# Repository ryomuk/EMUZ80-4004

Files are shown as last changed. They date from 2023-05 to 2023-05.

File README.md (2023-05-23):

# EMUZ80-4004
4004 mezzanine board for EMUZ80

This document is written mostly in Japanese. If necessary, please use a translation service such as DeepL (I recommend this) or Google.

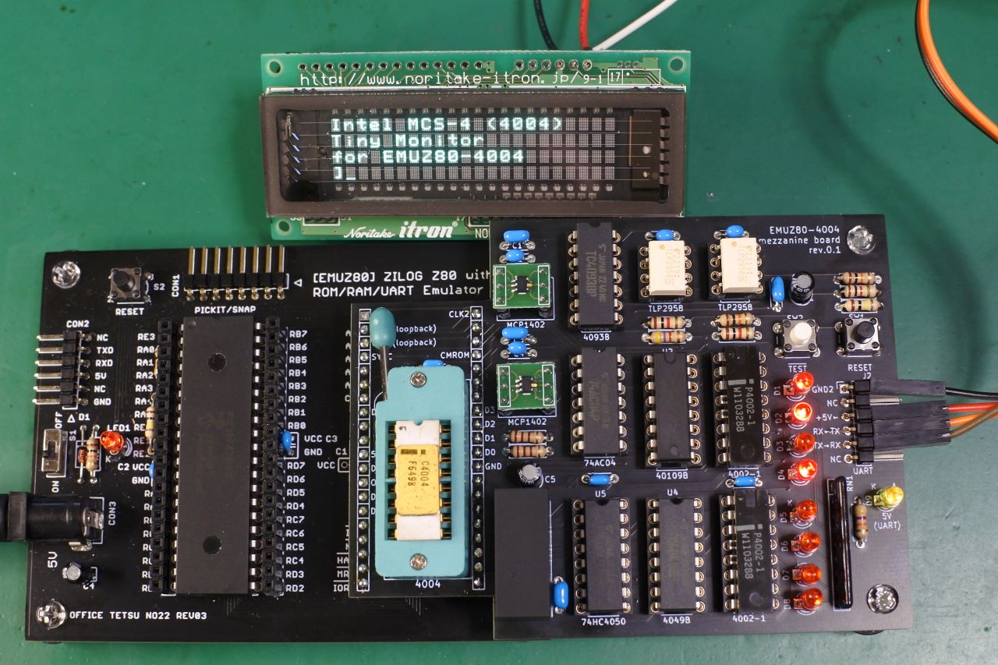
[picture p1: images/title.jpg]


## 概要
電脳伝説さん(@vintagechips)のEMUZ80( https://github.com/vintagechips/emuz80 )のZ80をIntel4004に差し替えるための基板(メザニンボード)，PIC用ファームウェア，4004用のデモプログラム(電卓)です．

別レポジトリにあるIntel4004評価ボード(test4004 https://github.com/ryomuk/test4004 )の4289とROMの機能をPIC上に実装したような作りになっています．
プログラムメモリ領域のRAMは実装しておらず，データ用メモリ(4002)も2つしか搭載していないので，test4004よりも小規模なシステムですが，とりあえずデモプログラムとして電卓が動作しています．

## このレポジトリの内容
- hardware/rev0.1 : メザニンボード作成用ファイル一式(KiCad 7用)
- src/PIC/emuz80_4004.X : PIC用ファームウェア(MPLAB IDE用のプロジェクトフォルダ)
- src/demo/calc : 電卓のデモプログラム(4004アセンブラ)

## 動画
Youtubeで関連動画を公開しています．
- https://www.youtube.com/@ryomukai/videos

## ブログ
関連する情報が書いてあるかも．
- [Intel 4004 関連記事の目次@ブログの練習](https://blog.goo.ne.jp/tk-80/e/3fa1e2972737c7b7d1b83f4e7bd648a2)

## 開発環境
- [The Macroassembler AS](http://john.ccac.rwth-aachen.de:8000/as/)
- [Microchip MPLAB IDE](https://www.microchip.com/en-us/tools-resources/develop/mplab-x-ide)

## 参考にした文献，サイト等 (敬称略, 順不同)
- vintagechips, [emuz80](https://github.com/vintagechips/emuz80)
- vintagechips, [EMUZ80が完成](https://vintagechips.wordpress.com/2022/03/05/emuz80_reference/)
- satoshiokue, [EMUZ80-6502](https://github.com/satoshiokue/EMUZ80-6502)． 他，各種メザニンボード
- Gazelle, [EMUZ80用ファームウェア](https://drive.google.com/drive/folders/1NaIIpzsUY3lptekcrJjwyvWTBNHIjUf1)
- kanpapa, [emu1802](https://github.com/kanpapa/emu1802)
- yyhayami, [emuz80_yyhayami](https://github.com/yyhayami/emuz80_yyhayami)

## 更新履歴
- 2023/5/23: 初版公開

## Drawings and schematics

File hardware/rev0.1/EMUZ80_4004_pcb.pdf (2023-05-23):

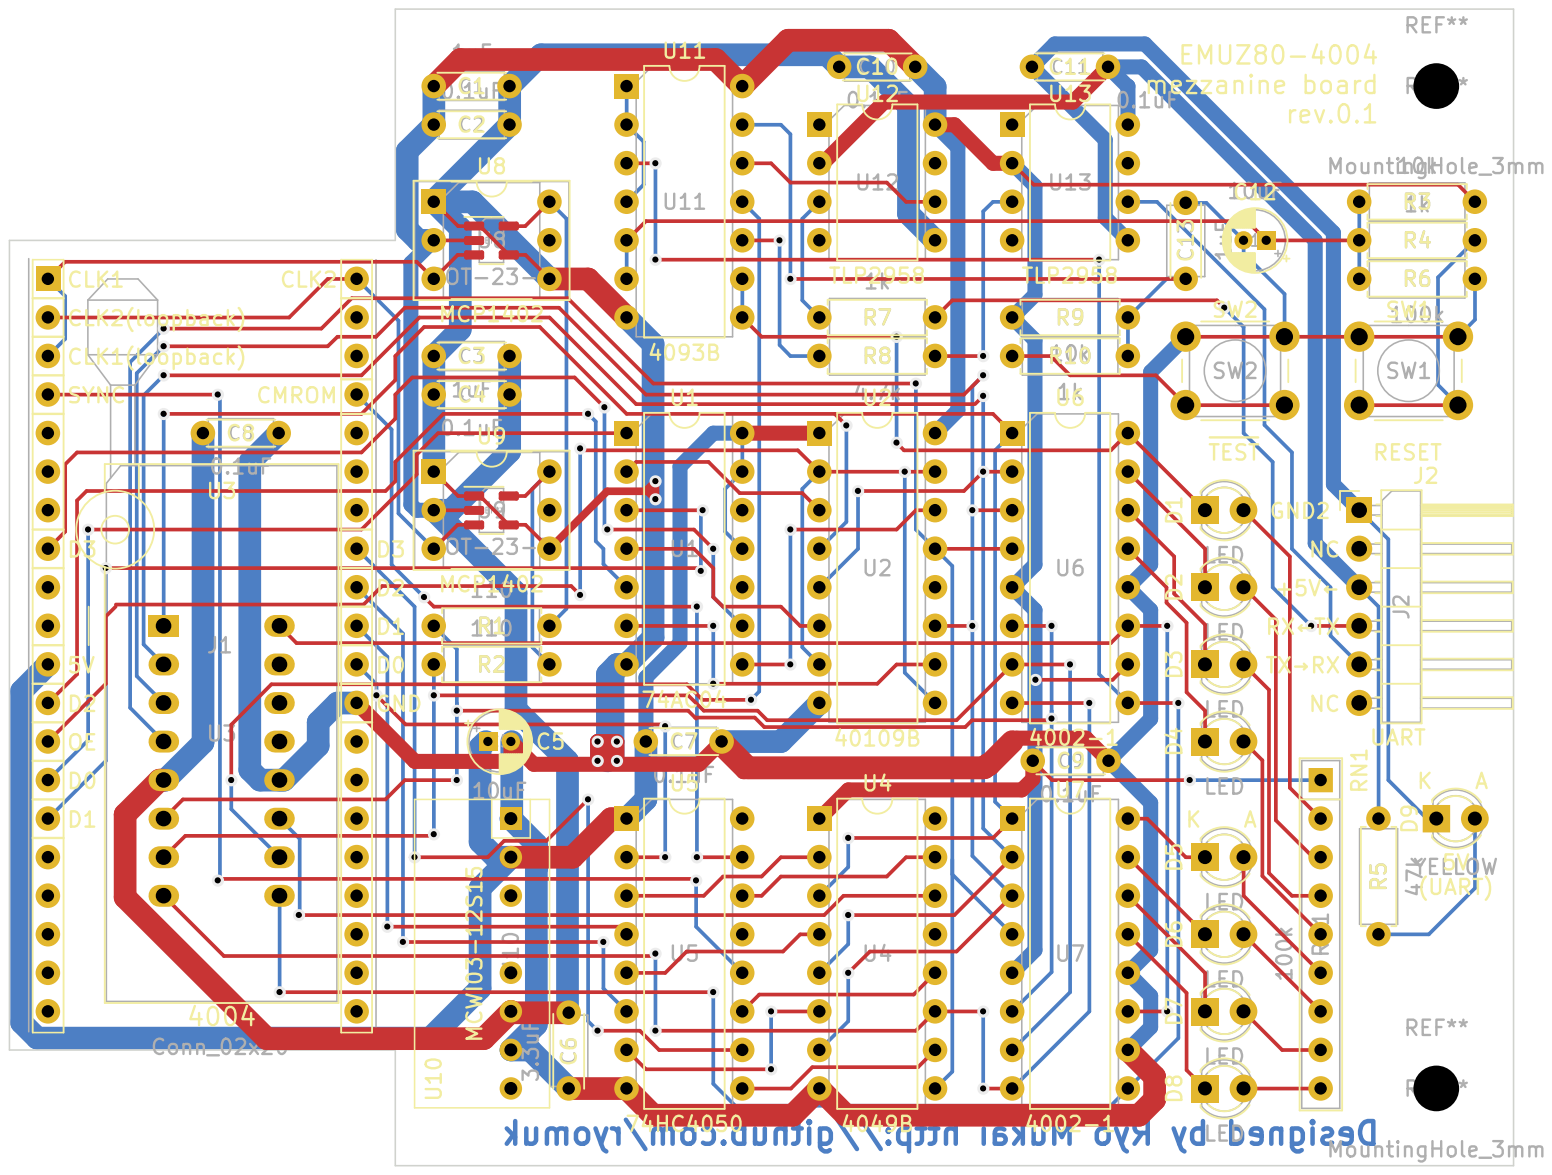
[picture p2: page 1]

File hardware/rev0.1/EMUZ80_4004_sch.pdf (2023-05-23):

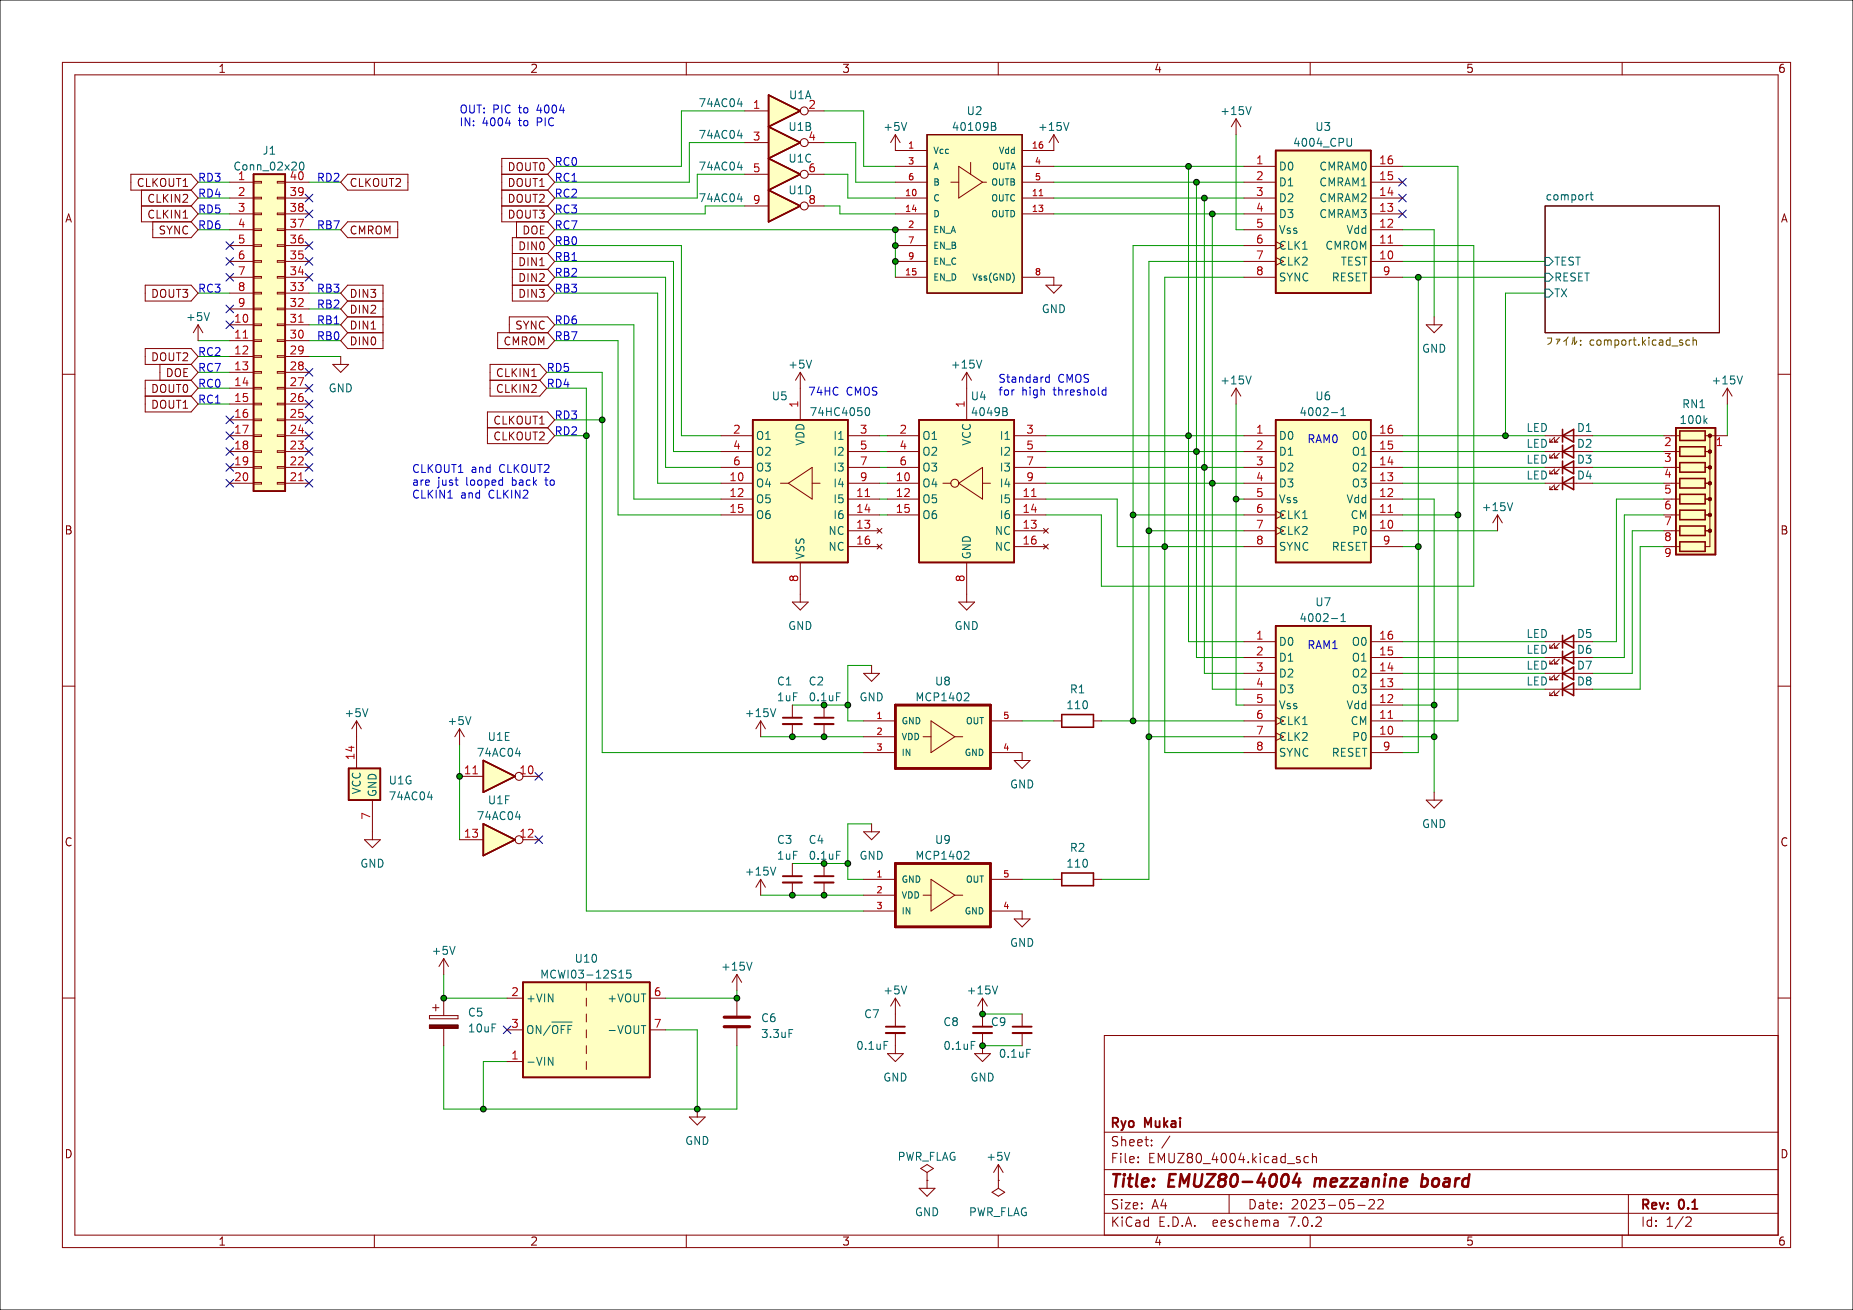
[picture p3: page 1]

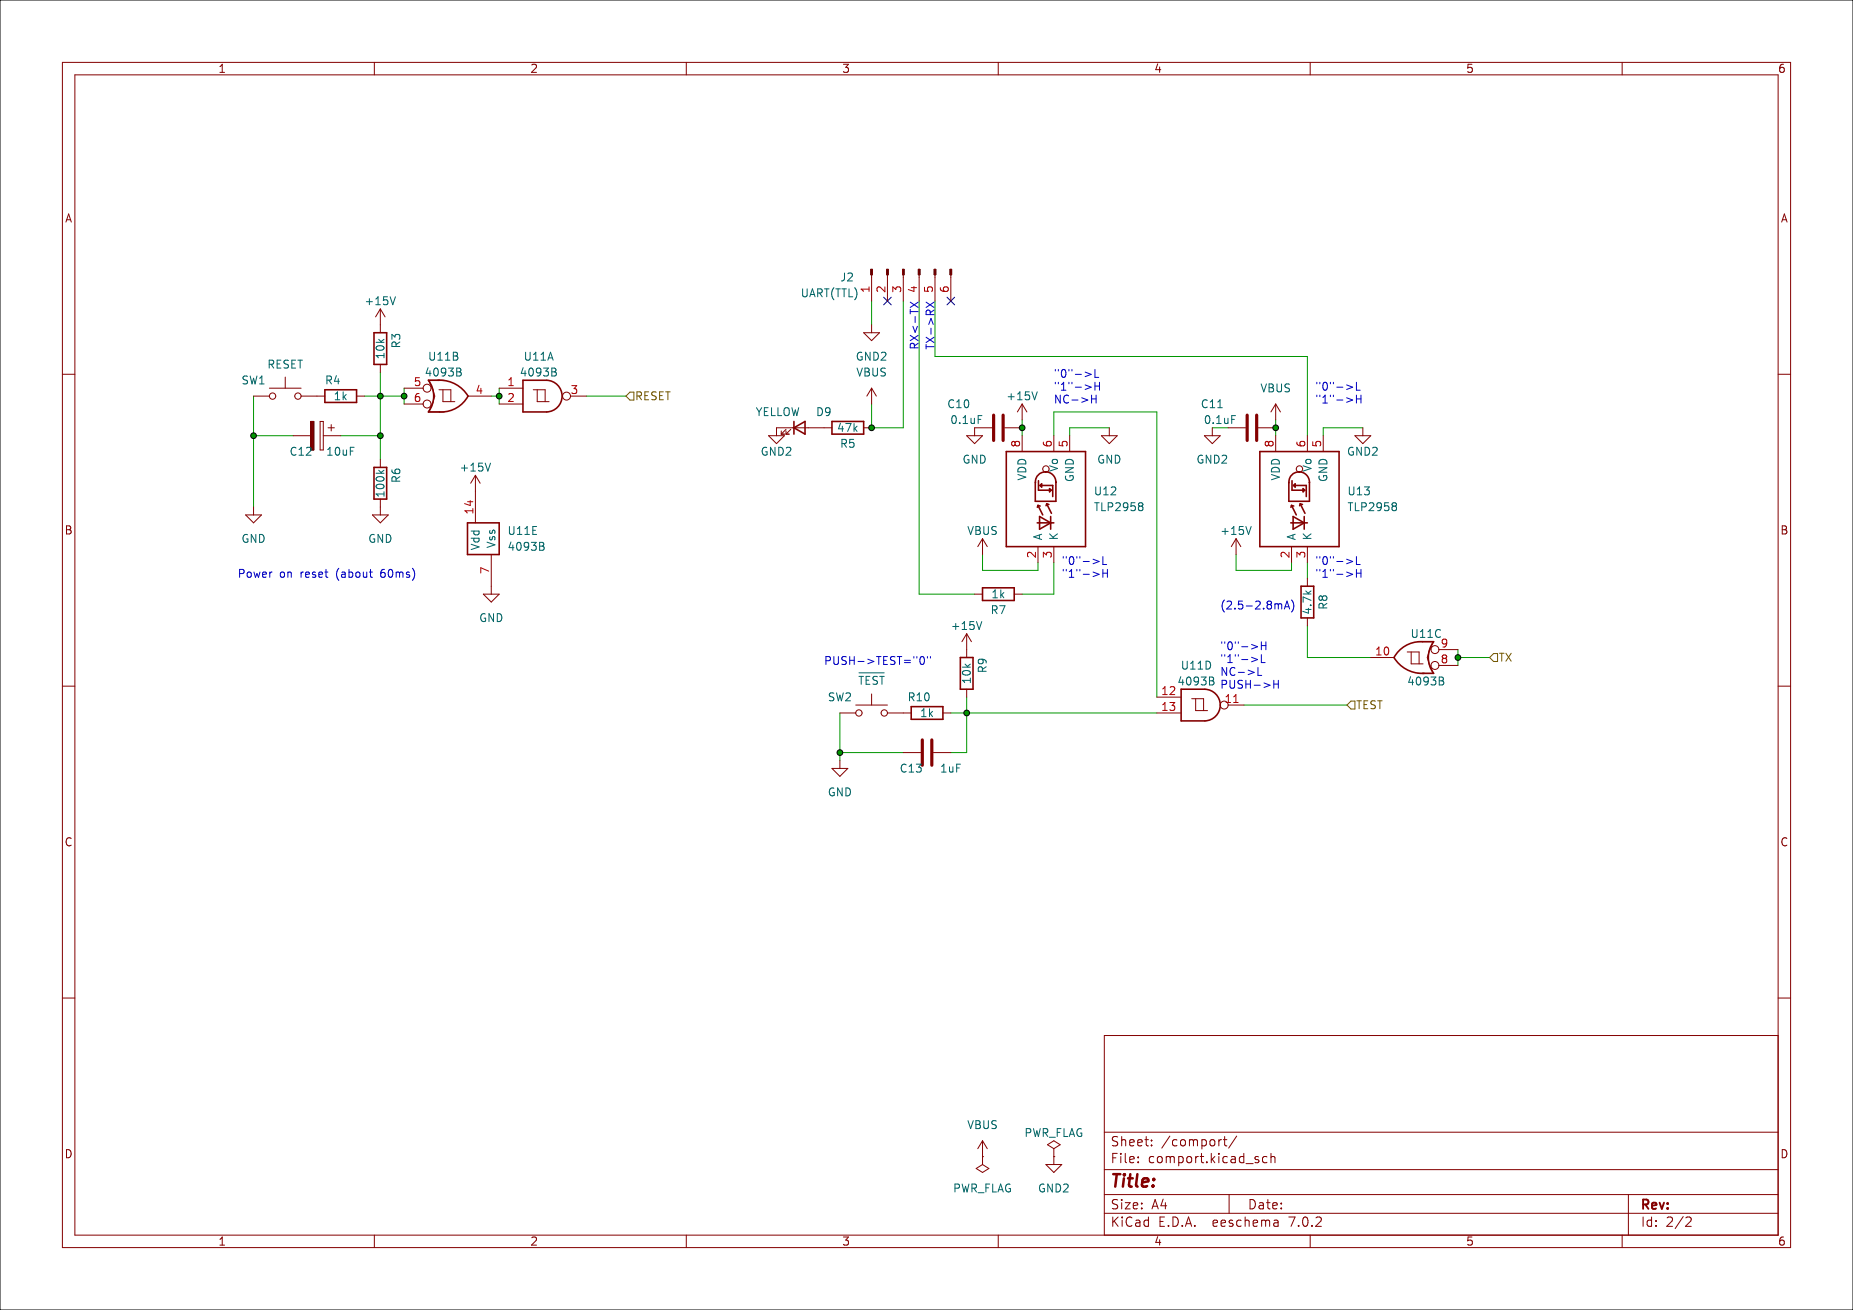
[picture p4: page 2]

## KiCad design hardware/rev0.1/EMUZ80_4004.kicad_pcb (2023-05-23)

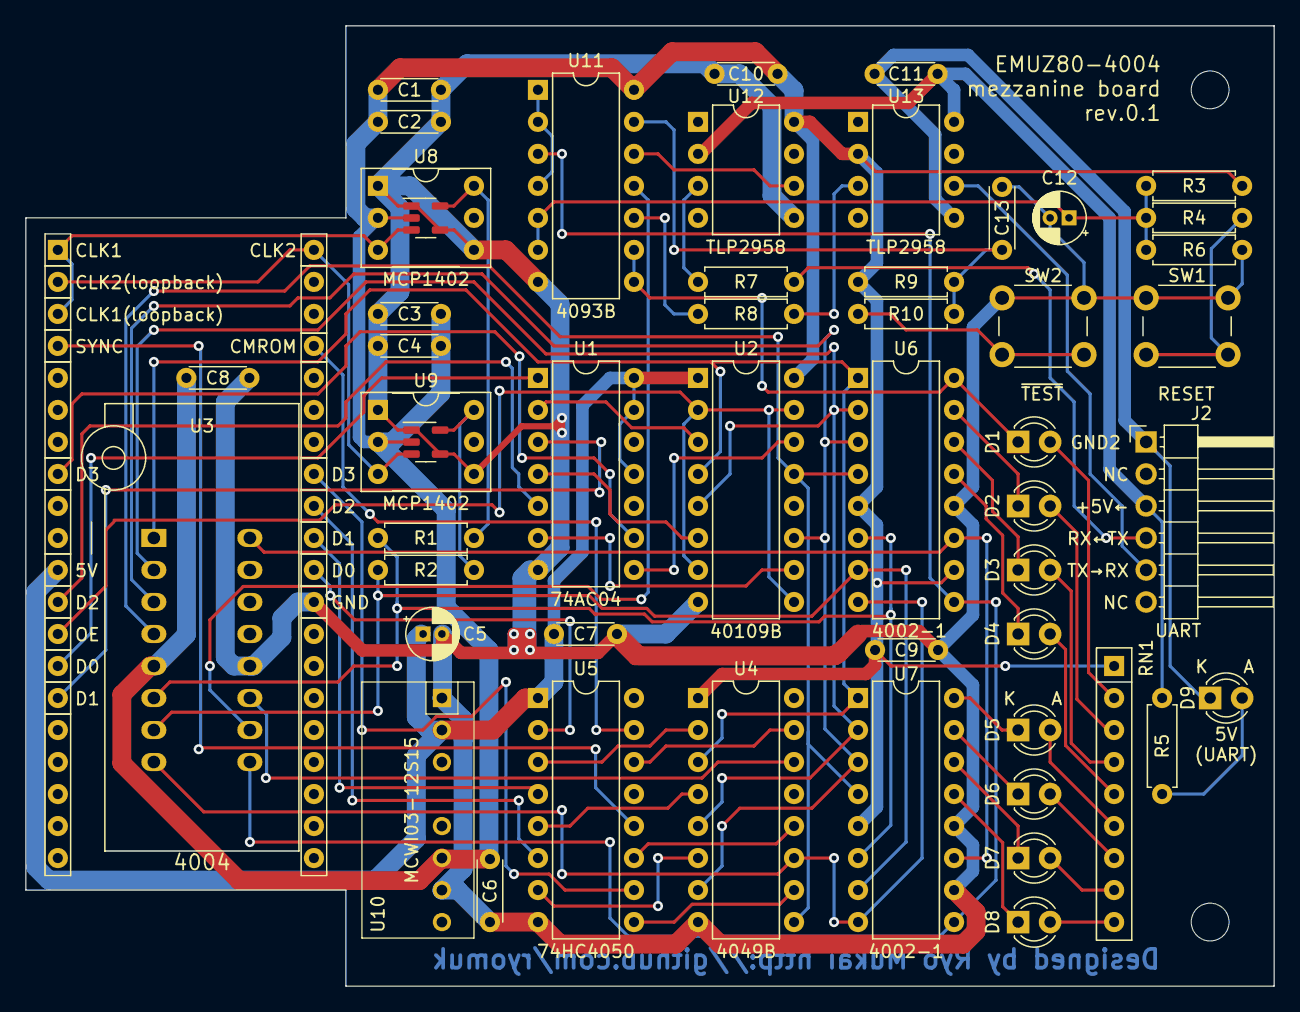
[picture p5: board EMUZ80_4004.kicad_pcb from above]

Board: 2 copper layers, 99.1 x 76.2 mm, 50 parts (0 on the bottom side), 69 nets.

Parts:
C1, C3: 1uF; C_Disc_D4.3mm_W1.9mm_P5.00mm
C2, C4, C7, C8, C9, C10, C11: 0.1uF; C_Disc_D4.3mm_W1.9mm_P5.00mm
C5, C12: 10uF; CP_Radial_D4.0mm_P1.50mm
C6: 3.3uF; C_Disc_D4.7mm_W2.5mm_P5.00mm
C13: 1uF; C_Disc_D4.7mm_W2.5mm_P5.00mm
D1, D2, D3, D4, D5, D6, D7, D8: LED; LED_D3.0mm
D9: YELLOW; LED_D3.0mm
J1: Conn_02x20; DIP-40_W20.32mm800mil_Socket
J2: UART; PinHeader_1x06_P2.54mm_Horizontal
R1, R2: 110; R_Axial_DIN0207_L6.3mm_D2.5mm_P7.62mm_Horizontal
R3, R9: 10k; R_Axial_DIN0207_L6.3mm_D2.5mm_P7.62mm_Horizontal
R4, R7, R10: 1k; R_Axial_DIN0207_L6.3mm_D2.5mm_P7.62mm_Horizontal
R5: 47k; R_Axial_DIN0207_L6.3mm_D2.5mm_P7.62mm_Horizontal
R6: 100k; R_Axial_DIN0207_L6.3mm_D2.5mm_P7.62mm_Horizontal
R8: 4.7k; R_Axial_DIN0207_L6.3mm_D2.5mm_P7.62mm_Horizontal
RN1: 100k; R_Array_SIP9
SW1: RESET; SW_PUSH_6mm_H4.3mm
SW2: ~{TEST}; SW_PUSH_6mm_H4.3mm
U1: 74AC04; DIP-14_W7.62mm
U2: 40109B; DIP-16_W7.62mm
U3: 4004; DIP_Socket-16_W4.3_W5.08_W7.62_W10.16_W10.9_3M_216-3340-00-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
U4: 4049B; DIP-16_W7.62mm
U5: 74HC4050; DIP-16_W7.62mm
U6, U7: 4002-1; DIP-16_W7.62mm
U8, U9: MCP1402; DIP-6_W7.62mm_Socket_5pin
U10: MCWI03-12S15; SIP-8_without4pin_for_DCDC
U11: 4093B; DIP-14_W7.62mm
U12, U13: TLP2958; DIP-8_W7.62mm

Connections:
+5V: C5.1, C7.1, J1.11, U1.11, U1.13, U1.14 (VCC), U2.1 (Vcc), U5.1 (VDD), U10.2 (+VIN)
+15V: C1.2, C2.2, C3.2, C4.2, C6.1, C8.1, C9.1, C10.2, R3.1, R9.1, RN1.1 (common), U2.16 (Vdd), U3.5 (Vss), U4.1 (VCC), U6.5 (Vss), U6.10 (P0), U7.5 (Vss), U8.2 (VDD), U9.2 (VDD), U10.6 (+VOUT), U11.14 (Vdd), U12.8 (VDD), U13.2 (A)
/comport/RESET: U3.9 (RESET), U6.9 (RESET), U7.9 (RESET), U11.3
/comport/TEST: U3.10 (TEST), U11.11
/comport/TX: D1.1 (K), U6.16 (O0), U11.8, U11.9
CLKIN1: J1.1, J1.3, U8.3 (IN)
CLKIN2: J1.2, J1.40, U9.3 (IN)
CMROM: J1.37, U5.15 (O6)
DIN0: J1.30, U5.2 (O1)
DIN1: J1.31, U5.4 (O2)
DIN2: J1.32, U5.6 (O3)
DIN3: J1.33, U5.10 (O4)
DOE: J1.13, U2.2 (EN_A), U2.7 (EN_B), U2.9 (EN_C), U2.15 (EN_D)
DOUT0: J1.14, U1.1
DOUT1: J1.15, U1.3
DOUT2: J1.12, U1.5
DOUT3: J1.8, U1.9
GND: C1.1, C2.1, C3.1, C4.1, C5.2, C6.2, C7.2, C8.2, C9.2, C10.1, C12.2, C13.2, J1.29, R6.2, SW1.1, SW2.1, U1.7 (GND), U2.8 (Vss(GND)), U3.12 (Vdd), U4.8 (GND), U5.8 (VSS), U6.12 (Vdd), U7.10 (P0), U7.12 (Vdd), U8.1 (GND), U8.4 (GND), U9.1 (GND), U9.4 (GND), U10.1 (-VIN), U10.7 (-VOUT), U11.7 (Vss), U12.5 (GND)
GND2: C11.1, D9.1 (K), J2.1, U13.5 (GND)
unnamed: C12.1, R3.2, R4.2, R6.1, U11.5, U11.6
unnamed: C13.1, R9.2, R10.2, U11.13
unnamed: D1.2 (A), RN1.2 (R1)
unnamed: D2.2 (A), RN1.3 (R2)
unnamed: D2.1 (K), U6.15 (O1)
unnamed: D3.2 (A), RN1.4 (R3)
unnamed: D3.1 (K), U6.14 (O2)
unnamed: D4.2 (A), RN1.5 (R4)
unnamed: D4.1 (K), U6.13 (O3)
unnamed: D5.2 (A), RN1.6 (R5)
unnamed: D5.1 (K), U7.16 (O0)
unnamed: D6.2 (A), RN1.7 (R6)
unnamed: D6.1 (K), U7.15 (O1)
unnamed: D7.2 (A), RN1.8 (R7)
unnamed: D7.1 (K), U7.14 (O2)
unnamed: D8.2 (A), RN1.9 (R8)
unnamed: D8.1 (K), U7.13 (O3)
unnamed: D9.2 (A), R5.1
unnamed: J2.4, R7.1
unnamed: J2.5, U13.6 (Vo)
unnamed: R4.1, SW1.2
unnamed: R8.1, U11.10
unnamed: R10.1, SW2.2
unnamed: U1.2, U2.3 (A)
unnamed: U1.4, U2.6 (B)
unnamed: U1.6, U2.10 (C)
unnamed: U1.8, U2.14 (D)
unnamed: U2.4 (OUTA), U3.1 (D0), U4.3 (I1), U6.1 (D0), U7.1 (D0)
unnamed: U2.5 (OUTB), U3.2 (D1), U4.5 (I2), U6.2 (D1), U7.2 (D1)
unnamed: U2.11 (OUTC), U3.3 (D2), U4.7 (I3), U6.3 (D2), U7.3 (D2)
unnamed: U2.13 (OUTD), U3.4 (D3), U4.9 (I4), U6.4 (D3), U7.4 (D3)
unnamed: R1.2, U3.6 (CLK1), U6.6 (CLK1), U7.6 (CLK1)
unnamed: R2.2, U3.7 (CLK2), U6.7 (CLK2), U7.7 (CLK2)
unnamed: U3.16 (CMRAM0), U6.11 (CM), U7.11 (CM)
unnamed: U3.11 (CMROM), U4.14 (I6)
unnamed: U3.8 (SYNC), U4.11 (I5), U6.8 (SYNC), U7.8 (SYNC)
unnamed: U4.2 (O1), U5.3 (I1)
unnamed: U4.4 (O2), U5.5 (I2)
unnamed: U4.6 (O3), U5.7 (I3)
unnamed: U4.10 (O4), U5.9 (I4)
unnamed: U4.12 (O5), U5.11 (I5)
unnamed: U4.15 (O6), U5.14 (I6)
unnamed: R1.1, U8.5 (OUT)
unnamed: R2.1, U9.5 (OUT)
unnamed: U11.1, U11.2, U11.4
unnamed: R7.2, U12.3 (K)
unnamed: U11.12, U12.6 (Vo)
unnamed: R8.2, U13.3 (K)
SYNC: J1.4, U5.12 (O5)
VBUS: C11.2, J2.3, R5.2, U12.2 (A), U13.8 (VDD)

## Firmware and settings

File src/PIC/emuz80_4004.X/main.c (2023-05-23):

/**
  Generated Main Source File

  Company:
    Microchip Technology Inc.

  File Name:
    main.c

  Summary:
    This is the main file generated using PIC10 / PIC12 / PIC16 / PIC18 MCUs

  Description:
    This header file provides implementations for driver APIs for all modules selected in the GUI.
    Generation Information :
        Product Revision  :  PIC10 / PIC12 / PIC16 / PIC18 MCUs - 1.81.8
        Device            :  PIC18F47Q43
        Driver Version    :  2.00
*/

/*
    (c) 2018 Microchip Technology Inc. and its subsidiaries. 
    
    Subject to your compliance with these terms, you may use Microchip software and any 
    derivatives exclusively with Microchip products. It is your responsibility to comply with third party 
    license terms applicable to your use of third party software (including open source software) that 
    may accompany Microchip software.
    
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
    IN NO EVENT WILL MICROCHIP BE LIABLE FOR ANY INDIRECT, SPECIAL, PUNITIVE, 
    INCIDENTAL OR CONSEQUENTIAL LOSS, DAMAGE, COST OR EXPENSE OF ANY KIND 
    WHATSOEVER RELATED TO THE SOFTWARE, HOWEVER CAUSED, EVEN IF MICROCHIP 
    HAS BEEN ADVISED OF THE POSSIBILITY OR THE DAMAGES ARE FORESEEABLE. TO 
    THE FULLEST EXTENT ALLOWED BY LAW, MICROCHIP'S TOTAL LIABILITY ON ALL 
    CLAIMS IN ANY WAY RELATED TO THIS SOFTWARE WILL NOT EXCEED THE AMOUNT 
    OF FEES, IF ANY, THAT YOU HAVE PAID DIRECTLY TO MICROCHIP FOR THIS 
    SOFTWARE.
*/

#include "mcc_generated_files/mcc.h"

typedef unsigned char byte;
typedef unsigned short word;

#define waitForRise(x) do{while(x); while(!x);}while(0)
#define waitForFall(x) do{while(!x); while(x);}while(0)
#define waitForBecomeLow(x) while(x){}
#define waitForBecomeHigh(x) while(!x){}

#define CLK1 CLK1_GetValue()
#define CLK2 CLK2_GetValue()
#define SYNC SYNC_GetValue()
#define CMROM CMROM_GetValue()

#define ROM_SIZE 0x1000 // 4kbytes
extern const byte rom[];

/*
                         Main application
 */

#define CMROMpos 7
#define DOEpos 7
#define CMROMbit ((byte)1 << CMROMpos)
#define DOEbit ((byte)1 << DOEpos)
#define DOEmask ~DOEbit

byte cmrom, opr, opa;
byte address_l;
void main(void)
{
 
  // Initialize the device
  SYSTEM_Initialize();

  // If using interrupts in PIC18 High/Low Priority Mode you need to enable the Global High and Low Interrupts
  // If using interrupts in PIC Mid-Range Compatibility Mode you need to enable the Global Interrupts
  // Use the following macros to:
  
  // Enable high priority global interrupts
  //INTERRUPT_GlobalInterruptHighEnable();
  
  // Enable low priority global interrupts.
  //INTERRUPT_GlobalInterruptLowEnable();
  
  // Disable high priority global interrupts
  INTERRUPT_GlobalInterruptHighDisable();
  
  // Disable low priority global interrupts.
  INTERRUPT_GlobalInterruptLowDisable();
  
  // CPU cycles
  //     A1  A2  A3  M1  M2  X1  X2  X3
  //CLK1~\_/~\_/~\_/~\_/~\_/~\_/~\_/~\_/
  //CLK2/~\_/~\_/~\_/~\_/~\_/~\_/~\_/~\_
  //
  // 2 phase clocks
  //      6    0    1    2    3    4    5    6    0
  // CLK1 ~~~~~\_________/~~~~~~~~~~~~~~~~~~~~~~~~\____
  //
  // CLK2 /~~~~~~~~~~~~~~~~~~~~~~~~\_________/~~~~~~~~~
  // BUS->CPU                       X__TRUE___X
  // CPU->BUS                  X_____TRUE_____X
 

  TBLPTRU = 1;    // TBLTPU 1 fixed ROM allocate 10000h
  while (1){
    // Add your application code
    // Cycle_X3
    DOE_SetLow();
#if 0
    TEST_SetHigh();
    TEST_SetLow();
    if(address_l & 1){TEST_SetHigh();}
    TEST_SetLow();
    if(address_l & 2){TEST_SetHigh();}
    TEST_SetLow();
    if(address_l & 4){TEST_SetHigh();}
    TEST_SetLow();
#endif    
    //waitForRise(SYNC);
    waitForFall(SYNC); // inverted to active high
    
    // Cycle_A1
    waitForFall(CLK2);
    address_l = PORTB & 0x0f;
    
    // Cycle_A2
    waitForFall(CLK2);
    address_l |=  PORTB <<4;
    
    // Cycle_A3
    waitForRise(CLK1);
    asm(
	"nop \n"
	"nop \n"
	//"nop \n"
	//"nop \n"
	);
    TEST_SetHigh();
    TEST_SetLow();
    //    waitForFall(CLK2);
    asm(
	"movf    PORTB,w,c ;volatile    \n"
	"movwf   _cmrom^(0+1280),c      \n"
	"andlw   15                     \n"
	"movwf   tblptrh                \n"
	"movff   _address_l,tblptrl     \n"
	"tblrd   *                      \n"
	"movf    tablat,w               \n"
	"movwf   _opa^(0+1280),c        \n"
	"movwf   _opr^(0+1280),c        \n"
	"swapf   _opr^(0+1280),c        \n"
	);

    opr &= DOEmask;
    if(cmrom & CMROMbit){
      opr |= DOEbit;
    }

    // Cycle_M1
    LATC = opr;
    waitForFall(CLK2);
      
    opa &= DOEmask;
    if(cmrom & CMROMbit){
      opa |= DOEbit;
    }
    // Cycle_M2
    waitForRise(CLK1);
    //    waitForFall(CLK2);
    LATC = opa;
    
    // Cycle_X1
    waitForFall(CLK1);
    LATC = 0;
    //DOE_SetLow();

    waitForFall(CLK2);
    
    // Cycle_X2
    waitForFall(CLK2);
  }
}

//#define ROM_LED
#define ROM_CALC

#ifdef ROM_LED
const byte rom[ROM_SIZE]  __at(0x10000) = {
  0x2e,0x00,0x2f,0xea,0xe1,0x19,0x09,0xf2, // 000-007
  0xf2,0xf8,0xb4,0x50,0x10,0xa4,0x40,0x04, // 008-00F
  0xea,0xb3,0x70,0x12,0x71,0x12,0x72,0x12, // 010-017
  0x00,0x00,0xc0,0x00,0x00,0x00,0x00,0x00  // 018-01F
};
#endif // ROM_LED

#ifdef ROM_CALC
const byte rom[ROM_SIZE]  __at(0x10000) = {
  0xF0,0xFD,0x56,0x64,0xD2,0x56,0x7C,0x20, // 000-007
  0x46,0x57,0x00,0x20,0x0F,0x57,0x00,0x20, // 008-00F
  0x33,0x57,0x00,0x22,0x5D,0x56,0x28,0x56, // 010-017
  0x00,0x56,0x76,0x50,0x78,0x14,0x23,0x56, // 018-01F
  0x53,0x40,0x13,0x56,0x28,0x20,0x64,0x50, // 020-027
  0x66,0x1C,0x2F,0x50,0x47,0x41,0x00,0x20, // 028-02F
  0x77,0x50,0x66,0x1C,0x39,0x50,0x47,0x41, // 030-037
  0x2A,0x20,0x63,0x50,0x66,0x1C,0x41,0x42, // 038-03F
  0x00,0x20,0x6D,0x57,0x00,0x40,0x13,0x20, // 040-047
  0x4B,0x57,0x00,0x56,0x00,0x56,0x28,0x56, // 048-04F
  0x6A,0xA3,0xBA,0x20,0x52,0x57,0x00,0x56, // 050-057
  0x00,0x56,0x28,0x56,0x6A,0xA3,0xF1,0xF5, // 058-05F
  0xF1,0xF5,0xBB,0x56,0x53,0xC0,0xF0,0xA0, // 060-067
  0x92,0x14,0x6E,0x12,0x77,0xC1,0xF0,0xA1, // 068-06F
  0x93,0x14,0x76,0x12,0x77,0xC1,0xC0,0xC1, // 070-077
  0xA2,0x1C,0x85,0xF1,0xDD,0x93,0x14,0x86, // 078-07F
  0xF1,0xDA,0x93,0x14,0x86,0xC0,0xC1,0x20, // 080-087
  0x30,0x54,0xC8,0xDE,0xB1,0x21,0xD5,0xE0, // 088-08F
  0x2C,0x50,0x2E,0x00,0x54,0xD4,0x26,0xC0, // 090-097
  0x2C,0x20,0x2E,0x00,0x54,0xD4,0x2C,0x60, // 098-09F
  0x54,0xD4,0x2C,0x10,0x2E,0x50,0x54,0xD4, // 0A0-0A7
  0x54,0xFD,0x53,0x39,0x54,0x00,0x20,0x00, // 0A8-0AF
  0x55,0x92,0x56,0x5C,0x2C,0x60,0x2E,0x00, // 0B0-0B7
  0x53,0xA8,0x14,0xC0,0x77,0x98,0x76,0x98, // 0B8-0BF
  0x42,0x9D,0xFF,0xFF,0xFF,0xFF,0xFF,0xFF, // 0C0-0C7
  0xFF,0xFF,0xFF,0xFF,0xFF,0xFF,0xFF,0xFF, // 0C8-0CF
  0xFF,0xFF,0xFF,0xFF,0xFF,0xFF,0xFF,0xFF, // 0D0-0D7
  0xFF,0xFF,0xFF,0xFF,0xFF,0xFF,0xFF,0xFF, // 0D8-0DF
  0xFF,0xFF,0xFF,0xFF,0xFF,0xFF,0xFF,0xFF, // 0E0-0E7
  0xFF,0xFF,0xFF,0xFF,0xFF,0xFF,0xFF,0xFF, // 0E8-0EF
  0xFF,0xFF,0xFF,0xFF,0xFF,0xFF,0xFF,0xFF, // 0F0-0F7
  0xFF,0xFF,0xFF,0xFF,0xFF,0xFF,0xFF,0xFF, // 0F8-0FF
  0xDC,0xB4,0xD0,0xB7,0xF0,0xD4,0x84,0xF1, // 100-107
  0x8B,0xB6,0x27,0xE9,0x56,0x48,0x77,0x04, // 108-10F
  0x22,0x3A,0x56,0x28,0x27,0xEC,0x56,0x48, // 110-117
  0x27,0xED,0x56,0x48,0x27,0xEE,0x56,0x48, // 118-11F
  0x27,0xEF,0x56,0x48,0x56,0x53,0x74,0x02, // 120-127
  0x40,0x13,0xDC,0xB4,0xD0,0xB7,0xF0,0xD4, // 128-12F
  0x84,0xF1,0x8B,0xB6,0x56,0x00,0x56,0x6A, // 130-137
  0x27,0xA3,0xE0,0x56,0x48,0x77,0x2E,0x22, // 138-13F
  0x3A,0x56,0x28,0x56,0x00,0x56,0x6A,0x27, // 140-147
  0xA3,0xE4,0x56,0x48,0x56,0x00,0x56,0x6A, // 148-14F
  0x27,0xA3,0xE5,0x56,0x48,0x56,0x00,0x56, // 150-157
  0x6A,0x27,0xA3,0xE6,0x56,0x48,0x56,0x00, // 158-15F
  0x56,0x6A,0x27,0xA3,0xE7,0x56,0x48,0x56, // 160-167
  0x53,0x74,0x2C,0x40,0x13,0xFF,0xFF,0xFF, // 168-16F
  0xFF,0xFF,0xFF,0xFF,0xFF,0xFF,0xFF,0xFF, // 170-177
  0xFF,0xFF,0xFF,0xFF,0xFF,0xFF,0xFF,0xFF, // 178-17F
  0xFF,0xFF,0xFF,0xFF,0xFF,0xFF,0xFF,0xFF, // 180-187
  0xFF,0xFF,0xFF,0xFF,0xFF,0xFF,0xFF,0xFF, // 188-18F
  0xFF,0xFF,0xFF,0xFF,0xFF,0xFF,0xFF,0xFF, // 190-197
  0xFF,0xFF,0xFF,0xFF,0xFF,0xFF,0xFF,0xFF, // 198-19F
  0xFF,0xFF,0xFF,0xFF,0xFF,0xFF,0xFF,0xFF, // 1A0-1A7
  0xFF,0xFF,0xFF,0xFF,0xFF,0xFF,0xFF,0xFF, // 1A8-1AF
  0xFF,0xFF,0xFF,0xFF,0xFF,0xFF,0xFF,0xFF, // 1B0-1B7
  0xFF,0xFF,0xFF,0xFF,0xFF,0xFF,0xFF,0xFF, // 1B8-1BF
  0xFF,0xFF,0xFF,0xFF,0xFF,0xFF,0xFF,0xFF, // 1C0-1C7
  0xFF,0xFF,0xFF,0xFF,0xFF,0xFF,0xFF,0xFF, // 1C8-1CF
  0xFF,0xFF,0xFF,0xFF,0xFF,0xFF,0xFF,0xFF, // 1D0-1D7
  0xFF,0xFF,0xFF,0xFF,0xFF,0xFF,0xFF,0xFF, // 1D8-1DF
  0xFF,0xFF,0xFF,0xFF,0xFF,0xFF,0xFF,0xFF, // 1E0-1E7
  0xFF,0xFF,0xFF,0xFF,0xFF,0xFF,0xFF,0xFF, // 1E8-1EF
  0xFF,0xFF,0xFF,0xFF,0xFF,0xFF,0xFF,0xFF, // 1F0-1F7
  0xFF,0xFF,0xFF,0xFF,0xFF,0xFF,0xFF,0xFF, // 1F8-1FF
  0x20,0x59,0x57,0x00,0x52,0xF3,0xA6,0xF6, // 200-207
  0xD0,0xF5,0xB6,0xF0,0xB7,0x20,0x00,0x55, // 208-20F
  0x92,0x56,0x53,0x56,0x00,0x56,0x76,0x50, // 210-217
  0x78,0x14,0x21,0x56,0x53,0x53,0x05,0x42, // 218-21F
  0x06,0x20,0x71,0x50,0x66,0x1C,0x2B,0x56, // 220-227
  0x53,0x40,0x13,0x20,0x2B,0x50,0x66,0x1C, // 228-22F
  0x3B,0x56,0x28,0x56,0x53,0x53,0x39,0x52, // 230-237
  0xD2,0x42,0x06,0x20,0x2D,0x50,0x66,0x1C, // 238-23F
  0x4B,0x56,0x28,0x56,0x53,0x54,0x6D,0x52, // 240-247
  0xD2,0x42,0x06,0x20,0x2A,0x50,0x66,0x1C, // 248-24F
  0x5B,0x56,0x28,0x56,0x53,0x54,0x00,0x52, // 250-257
  0xD2,0x42,0x06,0x20,0x2F,0x50,0x66,0x1C, // 258-25F
  0x6B,0x56,0x28,0x56,0x53,0x54,0xFD,0x52, // 260-267
  0xD2,0x42,0x06,0x20,0x63,0x50,0x66,0x1C, // 268-26F
  0x77,0x56,0x53,0x52,0xF3,0x42,0x06,0x20, // 270-277
  0x73,0x50,0x66,0x1C,0x85,0x54,0xF6,0x56, // 278-27F
  0x53,0x52,0xD2,0x42,0x06,0x20,0x70,0x50, // 280-287
  0x66,0x1C,0x91,0x56,0x53,0x54,0x54,0x42, // 288-28F
  0x06,0x20,0x72,0x50,0x66,0x1C,0xA1,0x20, // 290-297
  0x96,0x57,0x00,0x40,0x87,0x52,0xD2,0x42, // 298-29F
  0x06,0xA6,0xF6,0xF6,0x12,0xC2,0x20,0x2E, // 2A0-2A7
  0x50,0x66,0x1C,0xB8,0xA6,0xF5,0x12,0xC2, // 2A8-2AF
  0x56,0x28,0x52,0xDE,0x52,0xED,0x42,0x13, // 2B0-2B7
  0x52,0xC4,0x14,0xC2,0x56,0x28,0x52,0xDE, // 2B8-2BF
  0x53,0x19,0x42,0x13,0x20,0x2F,0x50,0x66, // 2C0-2C7
  0x12,0xD1,0x20,0x39,0x50,0x66,0x1A,0xD1, // 2C8-2CF
  0xC1,0xC0,0xA6,0xF6,0xFA,0xF5,0xB6,0xC0, // 2D0-2D7
  0xA6,0xF6,0xF1,0xF5,0xB6,0xC0,0xA6,0xF6, // 2D8-2DF
  0x1A,0xE4,0x53,0x05,0xA7,0x1C,0xEC,0x67, // 2E0-2E7
  0x20,0x00,0x54,0xC8,0xC0,0xA6,0xF5,0xFA, // 2E8-2EF
  0xF6,0xB6,0xC0,0x20,0x00,0x54,0xC8,0x20, // 2F0-2F7
  0x10,0x54,0xC8,0x20,0x20,0x54,0xC8,0x20, // 2F8-2FF
  0x30,0x54,0xC8,0x42,0xD8,0x2C,0x30,0x2E, // 300-307
  0x20,0x54,0xD4,0x2C,0x20,0x2E,0x10,0x54, // 308-30F
  0xD4,0x2C,0x10,0x2E,0x00,0x54,0xD4,0x42, // 310-317
  0xD8,0x56,0x6A,0xA3,0x2E,0x00,0xDF,0xF1, // 318-31F
  0x97,0xBF,0x2F,0xA6,0xF5,0x12,0x29,0xA7, // 320-327
  0xE4,0xA3,0xE0,0x67,0xDF,0xF1,0x97,0x1C, // 328-32F
  0x38,0xA6,0xF6,0xF6,0xFA,0xF5,0xF5,0xB6, // 330-337
  0xC0,0x54,0xA6,0x2C,0x00,0x2E,0x10,0x2D, // 338-33F
  0xED,0xB0,0x2F,0xED,0xF1,0x90,0x14,0x68, // 340-347
  0x53,0xA8,0x14,0x70,0x12,0x60,0x2C,0x40, // 348-34F
  0x2E,0x00,0x54,0xD4,0x2C,0x00,0x2E,0x10, // 350-357
  0x54,0xD4,0x2C,0x10,0x2E,0x40,0x54,0xD4, // 358-35F
  0x2C,0x00,0x2E,0x10,0x53,0x96,0x43,0x6E, // 360-367
  0x2C,0x00,0x2E,0x10,0x53,0x87,0x43,0x76, // 368-36F
  0x20,0x00,0x54,0xC8,0x43,0x6E,0x20,0x00, // 370-377
  0x53,0xC2,0x2C,0x10,0x2E,0x20,0x54,0xD4, // 378-37F
  0x2C,0x20,0x2E,0x30,0x54,0xD4,0xC0,0xF0, // 380-387
  0xBD,0xF0,0xBF,0xF0,0x2F,0xE9,0x2D,0xEB, // 388-38F
  0xFB,0xE0,0x6D,0x7F,0x8C,0xC0,0xF0,0xBD, // 390-397
  0xF0,0xBF,0xF0,0xFA,0xF9,0x2F,0xE8,0xF1, // 398-39F
  0x2D,0xEB,0xFB,0xE0,0x6D,0x7F,0x9C,0xC0, // 3A0-3A7
  0xF0,0xB0,0xA0,0xF4,0xBD,0x2D,0xE9,0xB1, // 3A8-3AF
  0xA0,0xF4,0xBF,0x2F,0xA1,0xF1,0xE8,0x14, // 3B0-3B7
  0xBD,0x12,0xC1,0x43,0xC0,0x70,0xAA,0xC0, // 3B8-3BF
  0xC1,0xC1,0x21,0xEC,0xF4,0xB3,0xF0,0xB2, // 3C0-3C7
  0x43,0xD2,0xA2,0xF4,0xB1,0x21,0xE9,0x1C, // 3C8-3CF
  0xD4,0x62,0x73,0xCA,0xEC,0xF1,0x92,0xE4, // 3D0-3D7
  0xA2,0x54,0x87,0xDF,0xB1,0x21,0xE9,0x14, // 3D8-3DF
  0xE9,0xEC,0xF2,0xE4,0x1A,0xE8,0xD1,0xE6, // 3E0-3E7
  0xD1,0x44,0x71,0xFF,0xFF,0xFF,0xFF,0xFF, // 3E8-3EF
  0xFF,0xFF,0xFF,0xFF,0xFF,0xFF,0xFF,0xFF, // 3F0-3F7
  0xFF,0xFF,0xFF,0xFF,0xFF,0xFF,0xFF,0xFF, // 3F8-3FF
  0x20,0x00,0x54,0xEC,0x1C,0x24,0x20,0x10, // 400-407
  0x54,0xEC,0x1C,0x24,0x2C,0x00,0x2E,0x10, // 408-40F
  0x55,0x80,0x2D,0xE5,0xEC,0xB0,0x2F,0xEC, // 410-417
  0xF1,0x80,0x2D,0xE4,0x1A,0x20,0xD1,0xE6, // 418-41F
  0x54,0x2A,0x43,0x76,0x20,0x00,0x54,0xC8, // 420-427
  0x44,0x22,0x2C,0x40,0x2E,0x00,0x54,0xE4, // 428-42F
  0x20,0x00,0x54,0xCE,0x2A,0x40,0x2C,0x00, // 430-437
  0x2E,0x10,0x20,0x10,0xF0,0xB8,0xA8,0xF4, // 438-43F
  0xBB,0x2B,0xE9,0x14,0x4C,0xF4,0xF2,0xB9, // 440-447
  0x53,0x87,0x79,0x48,0xD1,0x20,0x10,0x54, // 448-44F
  0x71,0x78,0x3E,0xC0,0x20,0x00,0x55,0x8B, // 450-457
  0x56,0x53,0x20,0x10,0x55,0x8B,0x56,0x53, // 458-45F
  0x20,0x20,0x55,0x8B,0x56,0x53,0x20,0x30, // 460-467
  0x55,0x8B,0x56,0x53,0xC0,0x54,0xF6,0x43, // 468-46F
  0x39,0x14,0x86,0xB3,0xA0,0xB2,0xF0,0xB1, // 470-477
  0xD0,0x12,0x7D,0x23,0xE9,0x21,0xE0,0x63, // 478-47F
  0xA3,0x1C,0x84,0xFA,0x71,0x78,0xC0,0x14, // 480-487
  0xA5,0xB5,0xA0,0xB2,0xF0,0xB4,0xD0,0xBF, // 488-48F
  0x12,0x98,0xA5,0xF4,0xB3,0x23,0xE9,0xBF, // 490-497
  0xA4,0xF4,0xB1,0x21,0xBF,0xE0,0x65,0xA5, // 498-49F
  0x1C,0xA3,0xFA,0x74,0x8E,0xC0,0x2C,0x00, // 4A0-4A7
  0x2E,0x10,0x2D,0xEC,0xBA,0x2F,0xEC,0xBB, // 4A8-4AF
  0xAB,0xF1,0x9A,0x12,0xC0,0xF4,0xF2,0x20, // 4B0-4B7
  0x10,0x54,0x71,0xAA,0x2F,0xE4,0x44,0xC7, // 4B8-4BF
  0x20,0x00,0x54,0x71,0xAB,0x2D,0xE4,0xC0, // 4C0-4C7
  0xF0,0x21,0xE4,0xE5,0xE6,0xE7,0xF0,0x21, // 4C8-4CF
  0xE0,0x71,0xCF,0xC0,0x2F,0xEC,0x2D,0xE4, // 4D0-4D7
  0x2F,0xED,0x2D,0xE5,0x2F,0xEE,0x2D,0xE6, // 4D8-4DF
  0x2F,0xEF,0x2D,0xE7,0x2F,0xE9,0x2D,0xE0, // 4E0-4E7
  0x6D,0x7F,0xE4,0xC0,0xF0,0xB1,0x21,0xE9, // 4E8-4EF
  0x1C,0xF5,0x71,0xEE,0xC1,0xC0,0x2E,0x00, // 4F0-4F7
  0x2F,0xED,0xF4,0xE5,0xC0,0x20,0x00,0x53, // 4F8-4FF
  0xC2,0x54,0xEC,0x1C,0x41,0x20,0x10,0x54, // 500-507
  0xEC,0x1C,0x47,0x2C,0x00,0x2E,0x10,0x55, // 508-50F
  0x80,0x2F,0xE5,0x2D,0xEC,0x1C,0x2A,0x2F, // 510-517
  0xEC,0xF2,0xE4,0x1A,0x1F,0xD1,0xE6,0xDE, // 518-51F
  0xBD,0x2D,0xE9,0x1C,0x3D,0xD1,0x54,0x87, // 520-527
  0x45,0x17,0x2D,0xEC,0xF8,0xB0,0x2F,0xEC, // 528-52F
  0xF1,0x90,0xE4,0x12,0x3D,0xF4,0xF2,0x20, // 530-537
  0x10,0x54,0x71,0xF0,0xE4,0x55,0x4C,0x43, // 538-53F
  0x76,0x20,0x00,0x21,0xD2,0xE6,0xC0,0x20, // 540-547
  0x00,0x54,0xC8,0xC0,0x2C,0x10,0x2E,0x00, // 548-54F
  0x2A,0x40,0x20,0x40,0x54,0xCE,0xD1,0xB8, // 550-557
  0xF0,0xB9,0x53,0xA8,0x1A,0x68,0xD9,0xF1, // 558-55F
  0x99,0x14,0x68,0x53,0x96,0x69,0x45,0x5A, // 560-567
  0xA8,0xF4,0xBB,0x2B,0xA9,0xE0,0xD1,0x20, // 568-56F
  0x00,0x54,0x71,0x78,0x58,0x2C,0x00,0x2E, // 570-577
  0x10,0x54,0xD4,0x2E,0x40,0x54,0xE4,0xC0, // 578-57F
  0x2D,0xED,0xB0,0x2F,0xED,0xF1,0x90,0x14, // 580-587
  0x8A,0xCF,0xC0,0x22,0x58,0x56,0x28,0xA0, // 588-58F
  0x56,0x48,0x22,0x3D,0x21,0xEE,0x14,0x9A, // 590-597
  0x22,0x45,0x56,0x28,0x22,0x2B,0x21,0xED, // 598-59F
  0x14,0xA4,0x22,0x2D,0x56,0x28,0x21,0xEC, // 5A0-5A7
  0xBA,0xDF,0xB1,0x21,0xE9,0x14,0xB1,0x56, // 5A8-5AF
  0x48,0xAA,0x1C,0xB8,0x22,0x2E,0x56,0x28, // 5B0-5B7
  0xF0,0xD1,0xBB,0xDF,0xF1,0x9B,0x14,0xD0, // 5B8-5BF
  0xB1,0x21,0xE9,0x56,0x48,0xF0,0xAA,0x9B, // 5C0-5C7
  0x1C,0xCE,0x22,0x2E,0x56,0x28,0x7B,0xBB, // 5C8-5CF
  0xC0,0xFF,0xFF,0xFF,0xFF,0xFF,0xFF,0xFF, // 5D0-5D7
  0xFF,0xFF,0xFF,0xFF,0xFF,0xFF,0xFF,0xFF, // 5D8-5DF
  0xFF,0xFF,0xFF,0xFF,0xFF,0xFF,0xFF,0xFF, // 5E0-5E7
  0xFF,0xFF,0xFF,0xFF,0xFF,0xFF,0xFF,0xFF, // 5E8-5EF
  0xFF,0xFF,0xFF,0xFF,0xFF,0xFF,0xFF,0xFF, // 5F0-5F7
  0xFF,0xFF,0xFF,0xFF,0xFF,0xFF,0xFF,0xFF, // 5F8-5FF
  0x2C,0x0C,0x19,0x02,0x2E,0x0C,0x7F,0x06, // 600-607
  0x19,0x0D,0xF1,0x46,0x10,0xFA,0x00,0x00, // 608-60F
  0xF6,0x00,0x7D,0x08,0xB3,0x2C,0x0C,0x19, // 610-617
  0x1C,0xF1,0x46,0x1F,0xFA,0x00,0x00,0xF6, // 618-61F
  0x00,0x7D,0x17,0xB2,0x19,0x27,0xC1,0xC0, // 620-627
  0x2E,0x00,0x2F,0x2C,0x0B,0xA3,0xF1,0xF5, // 628-62F
  0x00,0x00,0x00,0x00,0x00,0xE1,0xF6,0x7D, // 630-637
  0x30,0x2C,0x0B,0xA2,0xFA,0x00,0x00,0xE1, // 638-63F
  0x2E,0x0E,0x7F,0x42,0xF6,0x7D,0x3F,0xC0, // 640-647
  0x22,0x30,0xF1,0xFB,0x1A,0x50,0x62,0xF2, // 648-64F
  0xB3,0x46,0x28,0x22,0x0D,0x56,0x28,0x22, // 650-657
  0x0A,0x56,0x28,0xC0,0x22,0x0D,0x46,0x28, // 658-65F
  0x22,0x0A,0x46,0x28,0x2E,0x00,0x2F,0xD1, // 660-667
  0xE1,0xC0,0xF0,0xD3,0x92,0x14,0x73,0xF0, // 668-66F
  0xD9,0x83,0xB3,0xF0,0xB2,0xC0,0x2E,0x40, // 670-677
  0x2F,0xA3,0xE1,0xC0,0xF4,0xF2,0xBB,0xD0, // 678-67F
  0x2E,0x40,0x56,0x87,0x7B,0x7F,0xC0,0x2F, // 680-687
  0xD8,0xE1,0xD8,0x56,0x90,0xD0,0xE1,0xC0, // 688-68F
  0x2C,0x45,0x2E,0xEF,0x7C,0x94,0x7D,0x94, // 690-697
  0x7E,0x94,0x7F,0x94,0xF8,0x1C,0x90,0xC0, // 698-69F
  0xFF,0xFF,0xFF,0xFF,0xFF,0xFF,0xFF,0xFF, // 6A0-6A7
  0xFF,0xFF,0xFF,0xFF,0xFF,0xFF,0xFF,0xFF, // 6A8-6AF
  0xFF,0xFF,0xFF,0xFF,0xFF,0xFF,0xFF,0xFF, // 6B0-6B7
  0xFF,0xFF,0xFF,0xFF,0xFF,0xFF,0xFF,0xFF, // 6B8-6BF
  0xFF,0xFF,0xFF,0xFF,0xFF,0xFF,0xFF,0xFF, // 6C0-6C7
  0xFF,0xFF,0xFF,0xFF,0xFF,0xFF,0xFF,0xFF, // 6C8-6CF
  0xFF,0xFF,0xFF,0xFF,0xFF,0xFF,0xFF,0xFF, // 6D0-6D7
  0xFF,0xFF,0xFF,0xFF,0xFF,0xFF,0xFF,0xFF, // 6D8-6DF
  0xFF,0xFF,0xFF,0xFF,0xFF,0xFF,0xFF,0xFF, // 6E0-6E7
  0xFF,0xFF,0xFF,0xFF,0xFF,0xFF,0xFF,0xFF, // 6E8-6EF
  0xFF,0xFF,0xFF,0xFF,0xFF,0xFF,0xFF,0xFF, // 6F0-6F7
  0xFF,0xFF,0xFF,0xFF,0xFF,0xFF,0xFF,0xFF, // 6F8-6FF
  0x32,0xA2,0x14,0x0B,0x56,0x28,0x71,0x00, // 700-707
  0x60,0x47,0x00,0xA3,0x1C,0x04,0xC0,0x0D, // 708-70F
  0x49,0x6E,0x74,0x65,0x6C,0x20,0x4D,0x43, // 710-717
  0x53,0x2D,0x34,0x20,0x28,0x34,0x30,0x30, // 718-71F
  0x34,0x29,0x0D,0x0A,0x54,0x69,0x6E,0x79, // 720-727
  0x20,0x4D,0x6F,0x6E,0x69,0x74,0x6F,0x72, // 728-72F
  0x0D,0x0A,0x00,0x0D,0x66,0x6F,0x72,0x20, // 730-737
  0x45,0x4D,0x55,0x5A,0x38,0x30,0x2D,0x34, // 738-73F
  0x30,0x30,0x34,0x0D,0x0A,0x00,0x1B,0x40, // 740-747
  0x1F,0x02,0x00,0x20,0x42,0x41,0x4E,0x4B, // 748-74F
  0x3D,0x00,0x20,0x43,0x48,0x49,0x50,0x3D, // 750-757
  0x00,0x0D,0x0A,0x43,0x61,0x6C,0x63,0x75, // 758-75F
  0x6C,0x61,0x74,0x6F,0x72,0x20,0x4D,0x6F, // 760-767
  0x64,0x65,0x0D,0x0A,0x00,0x0D,0x0A,0x64, // 768-76F
  0x3A,0x64,0x75,0x6D,0x70,0x20,0x52,0x41, // 770-777
  0x4D,0x2C,0x20,0x77,0x3A,0x77,0x72,0x69, // 778-77F
  0x74,0x65,0x20,0x52,0x41,0x4D,0x2C,0x20, // 780-787
  0x63,0x3A,0x43,0x61,0x6C,0x63,0x20,0x6D, // 788-78F
  0x6F,0x64,0x65,0x0D,0x0A,0x00,0x20,0x53, // 790-797
  0x51,0x52,0x0D,0x0A,0x00,0x32,0xC0,0x00, // 798-79F
  0x00,0x00,0x00,0x00,0x00,0x00,0x00,0x00, // 7A0-7A7
  0x00,0x00,0x00,0x00,0x00,0x00,0x00,0x00, // 7A8-7AF
  0x00,0x00,0x00,0x00,0x00,0x00,0x00,0x00, // 7B0-7B7
  0x00,0x00,0x00,0x00,0x00,0x00,0x00,0x00, // 7B8-7BF
  0x00,0x00,0x00,0x00,0x00,0x00,0x00,0x00, // 7C0-7C7
  0x00,0x00,0x00,0x00,0x00,0x00,0x00,0x00, // 7C8-7CF
  0x00,0x00,0x00,0x00,0x00,0x00,0x00,0x00, // 7D0-7D7
  0x00,0x00,0x00,0x00,0x00,0x00,0x00,0x00, // 7D8-7DF
  0x00,0x00,0x00,0x00,0x00,0x00,0x00,0x00, // 7E0-7E7
  0x00,0x00,0x00,0x00,0x00,0x00,0x00,0x00, // 7E8-7EF
  0x00,0x00,0x00,0x00,0x00,0x00,0x00,0x00, // 7F0-7F7
  0x00,0x00,0x00,0x00,0x00,0x00,0x00,0x00, // 7F8-7FF
  0x00,0x00,0x00,0x00,0x00,0x00,0x00,0x00, // 800-807
  0x00,0x00,0x00,0x00,0x00,0x00,0x00,0x00, // 808-80F
  0x00,0x00,0x00,0x00,0x00,0x00,0x00,0x00, // 810-817
  0x00,0x00,0x00,0x00,0x00,0x00,0x00,0x00, // 818-81F
  0x00,0x00,0x00,0x00,0x00,0x00,0x00,0x00, // 820-827
  0x00,0x00,0x00,0x00,0x00,0x00,0x00,0x00, // 828-82F
  0x00,0x00,0x00,0x00,0x00,0x00,0x00,0x00, // 830-837
  0x00,0x00,0x00,0x00,0x00,0x00,0x00,0x00, // 838-83F
  0x00,0x00,0x00,0x00,0x00,0x00,0x00,0x00, // 840-847
  0x00,0x00,0x00,0x00,0x00,0x00,0x00,0x00, // 848-84F
  0x00,0x00,0x00,0x00,0x00,0x00,0x00,0x00, // 850-857
  0x00,0x00,0x00,0x00,0x00,0x00,0x00,0x00, // 858-85F
  0x00,0x00,0x00,0x00,0x00,0x00,0x00,0x00, // 860-867
  0x00,0x00,0x00,0x00,0x00,0x00,0x00,0x00, // 868-86F
  0x00,0x00,0x00,0x00,0x00,0x00,0x00,0x00, // 870-877
  0x00,0x00,0x00,0x00,0x00,0x00,0x00,0x00, // 878-87F
  0x00,0x00,0x00,0x00,0x00,0x00,0x00,0x00, // 880-887
  0x00,0x00,0x00,0x00,0x00,0x00,0x00,0x00, // 888-88F
  0x00,0x00,0x00,0x00,0x00,0x00,0x00,0x00, // 890-897
  0x00,0x00,0x00,0x00,0x00,0x00,0x00,0x00, // 898-89F
  0x00,0x00,0x00,0x00,0x00,0x00,0x00,0x00, // 8A0-8A7
  0x00,0x00,0x00,0x00,0x00,0x00,0x00,0x00, // 8A8-8AF
  0x00,0x00,0x00,0x00,0x00,0x00,0x00,0x00, // 8B0-8B7
  0x00,0x00,0x00,0x00,0x00,0x00,0x00,0x00, // 8B8-8BF
  0x00,0x00,0x00,0x00,0x00,0x00,0x00,0x00, // 8C0-8C7
  0x00,0x00,0x00,0x00,0x00,0x00,0x00,0x00, // 8C8-8CF
  0x00,0x00,0x00,0x00,0x00,0x00,0x00,0x00, // 8D0-8D7
  0x00,0x00,0x00,0x00,0x00,0x00,0x00,0x00, // 8D8-8DF
  0x00,0x00,0x00,0x00,0x00,0x00,0x00,0x00, // 8E0-8E7
  0x00,0x00,0x00,0x00,0x00,0x00,0x00,0x00, // 8E8-8EF
  0x00,0x00,0x00,0x00,0x00,0x00,0x00,0x00, // 8F0-8F7
  0x00,0x00,0x00,0x00,0x00,0x00,0x00,0x00, // 8F8-8FF
  0x00,0x00,0x00,0x00,0x00,0x00,0x00,0x00, // 900-907
  0x00,0x00,0x00,0x00,0x00,0x00,0x00,0x00, // 908-90F
  0x00,0x00,0x00,0x00,0x00,0x00,0x00,0x00, // 910-917
  0x00,0x00,0x00,0x00,0x00,0x00,0x00,0x00, // 918-91F
  0x00,0x00,0x00,0x00,0x00,0x00,0x00,0x00, // 920-927
  0x00,0x00,0x00,0x00,0x00,0x00,0x00,0x00, // 928-92F
  0x00,0x00,0x00,0x00,0x00,0x00,0x00,0x00, // 930-937
  0x00,0x00,0x00,0x00,0x00,0x00,0x00,0x00, // 938-93F
  0x00,0x00,0x00,0x00,0x00,0x00,0x00,0x00, // 940-947
  0x00,0x00,0x00,0x00,0x00,0x00,0x00,0x00, // 948-94F
  0x00,0x00,0x00,0x00,0x00,0x00,0x00,0x00, // 950-957
  0x00,0x00,0x00,0x00,0x00,0x00,0x00,0x00, // 958-95F
  0x00,0x00,0x00,0x00,0x00,0x00,0x00,0x00, // 960-967
  0x00,0x00,0x00,0x00,0x00,0x00,0x00,0x00, // 968-96F
  0x00,0x00,0x00,0x00,0x00,0x00,0x00,0x00, // 970-977
  0x00,0x00,0x00,0x00,0x00,0x00,0x00,0x00, // 978-97F
  0x00,0x00,0x00,0x00,0x00,0x00,0x00,0x00, // 980-987
  0x00,0x00,0x00,0x00,0x00,0x00,0x00,0x00, // 988-98F
  0x00,0x00,0x00,0x00,0x00,0x00,0x00,0x00, // 990-997
  0x00,0x00,0x00,0x00,0x00,0x00,0x00,0x00, // 998-99F
  0x00,0x00,0x00,0x00,0x00,0x00,0x00,0x00, // 9A0-9A7
  0x00,0x00,0x00,0x00,0x00,0x00,0x00,0x00, // 9A8-9AF
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

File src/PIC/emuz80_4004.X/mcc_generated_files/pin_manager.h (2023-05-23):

/**
  @Generated Pin Manager Header File

  @Company:
    Microchip Technology Inc.

  @File Name:
    pin_manager.h

  @Summary:
    This is the Pin Manager file generated using PIC10 / PIC12 / PIC16 / PIC18 MCUs

  @Description
    This header file provides APIs for driver for .
    Generation Information :
        Product Revision  :  PIC10 / PIC12 / PIC16 / PIC18 MCUs - 1.81.8
        Device            :  PIC18F47Q43
        Driver Version    :  2.11
    The generated drivers are tested against the following:
        Compiler          :  XC8 2.36 and above
        MPLAB 	          :  MPLAB X 6.00	
*/

/*
    (c) 2018 Microchip Technology Inc. and its subsidiaries. 
    
    Subject to your compliance with these terms, you may use Microchip software and any 
    derivatives exclusively with Microchip products. It is your responsibility to comply with third party 
    license terms applicable to your use of third party software (including open source software) that 
    may accompany Microchip software.
    
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
    IN NO EVENT WILL MICROCHIP BE LIABLE FOR ANY INDIRECT, SPECIAL, PUNITIVE, 
    INCIDENTAL OR CONSEQUENTIAL LOSS, DAMAGE, COST OR EXPENSE OF ANY KIND 
    WHATSOEVER RELATED TO THE SOFTWARE, HOWEVER CAUSED, EVEN IF MICROCHIP 
    HAS BEEN ADVISED OF THE POSSIBILITY OR THE DAMAGES ARE FORESEEABLE. TO 
    THE FULLEST EXTENT ALLOWED BY LAW, MICROCHIP'S TOTAL LIABILITY ON ALL 
    CLAIMS IN ANY WAY RELATED TO THIS SOFTWARE WILL NOT EXCEED THE AMOUNT 
    OF FEES, IF ANY, THAT YOU HAVE PAID DIRECTLY TO MICROCHIP FOR THIS 
    SOFTWARE.
*/

#ifndef PIN_MANAGER_H
#define PIN_MANAGER_H

/**
  Section: Included Files
*/

#include <xc.h>

#define INPUT   1
#define OUTPUT  0

#define HIGH    1
#define LOW     0

#define ANALOG      1
#define DIGITAL     0

#define PULL_UP_ENABLED      1
#define PULL_UP_DISABLED     0

// get/set TEST aliases
#define TEST_TRIS                 TRISAbits.TRISA0
#define TEST_LAT                  LATAbits.LATA0
#define TEST_PORT                 PORTAbits.RA0
#define TEST_WPU                  WPUAbits.WPUA0
#define TEST_OD                   ODCONAbits.ODCA0
#define TEST_ANS                  ANSELAbits.ANSELA0
#define TEST_SetHigh()            do { LATAbits.LATA0 = 1; } while(0)
#define TEST_SetLow()             do { LATAbits.LATA0 = 0; } while(0)
#define TEST_Toggle()             do { LATAbits.LATA0 = ~LATAbits.LATA0; } while(0)
#define TEST_GetValue()           PORTAbits.RA0
#define TEST_SetDigitalInput()    do { TRISAbits.TRISA0 = 1; } while(0)
#define TEST_SetDigitalOutput()   do { TRISAbits.TRISA0 = 0; } while(0)
#define TEST_SetPullup()          do { WPUAbits.WPUA0 = 1; } while(0)
#define TEST_ResetPullup()        do { WPUAbits.WPUA0 = 0; } while(0)
#define TEST_SetPushPull()        do { ODCONAbits.ODCA0 = 0; } while(0)
#define TEST_SetOpenDrain()       do { ODCONAbits.ODCA0 = 1; } while(0)
#define TEST_SetAnalogMode()      do { ANSELAbits.ANSELA0 = 1; } while(0)
#define TEST_SetDigitalMode()     do { ANSELAbits.ANSELA0 = 0; } while(0)

// get/set DIN0 aliases
#define DIN0_TRIS                 TRISBbits.TRISB0
#define DIN0_LAT                  LATBbits.LATB0
#define DIN0_PORT                 PORTBbits.RB0
#define DIN0_WPU                  WPUBbits.WPUB0
#define DIN0_OD                   ODCONBbits.ODCB0
#define DIN0_ANS                  ANSELBbits.ANSELB0
#define DIN0_SetHigh()            do { LATBbits.LATB0 = 1; } while(0)
#define DIN0_SetLow()             do { LATBbits.LATB0 = 0; } while(0)
#define DIN0_Toggle()             do { LATBbits.LATB0 = ~LATBbits.LATB0; } while(0)
#define DIN0_GetValue()           PORTBbits.RB0
#define DIN0_SetDigitalInput()    do { TRISBbits.TRISB0 = 1; } while(0)
#define DIN0_SetDigitalOutput()   do { TRISBbits.TRISB0 = 0; } while(0)
#define DIN0_SetPullup()          do { WPUBbits.WPUB0 = 1; } while(0)
#define DIN0_ResetPullup()        do { WPUBbits.WPUB0 = 0; } while(0)
#define DIN0_SetPushPull()        do { ODCONBbits.ODCB0 = 0; } while(0)
#define DIN0_SetOpenDrain()       do { ODCONBbits.ODCB0 = 1; } while(0)
#define DIN0_SetAnalogMode()      do { ANSELBbits.ANSELB0 = 1; } while(0)
#define DIN0_SetDigitalMode()     do { ANSELBbits.ANSELB0 = 0; } while(0)

// get/set DIN1 aliases
#define DIN1_TRIS                 TRISBbits.TRISB1
#define DIN1_LAT                  LATBbits.LATB1
#define DIN1_PORT                 PORTBbits.RB1
#define DIN1_WPU                  WPUBbits.WPUB1
#define DIN1_OD                   ODCONBbits.ODCB1
#define DIN1_ANS                  ANSELBbits.ANSELB1
#define DIN1_SetHigh()            do { LATBbits.LATB1 = 1; } while(0)
#define DIN1_SetLow()             do { LATBbits.LATB1 = 0; } while(0)
#define DIN1_Toggle()             do { LATBbits.LATB1 = ~LATBbits.LATB1; } while(0)
#define DIN1_GetValue()           PORTBbits.RB1
#define DIN1_SetDigitalInput()    do { TRISBbits.TRISB1 = 1; } while(0)
#define DIN1_SetDigitalOutput()   do { TRISBbits.TRISB1 = 0; } while(0)
#define DIN1_SetPullup()          do { WPUBbits.WPUB1 = 1; } while(0)
#define DIN1_ResetPullup()        do { WPUBbits.WPUB1 = 0; } while(0)
#define DIN1_SetPushPull()        do { ODCONBbits.ODCB1 = 0; } while(0)
#define DIN1_SetOpenDrain()       do { ODCONBbits.ODCB1 = 1; } while(0)
#define DIN1_SetAnalogMode()      do { ANSELBbits.ANSELB1 = 1; } while(0)
#define DIN1_SetDigitalMode()     do { ANSELBbits.ANSELB1 = 0; } while(0)

// get/set DIN2 aliases
#define DIN2_TRIS                 TRISBbits.TRISB2
#define DIN2_LAT                  LATBbits.LATB2
#define DIN2_PORT                 PORTBbits.RB2
#define DIN2_WPU                  WPUBbits.WPUB2
#define DIN2_OD                   ODCONBbits.ODCB2
#define DIN2_ANS                  ANSELBbits.ANSELB2
#define DIN2_SetHigh()            do { LATBbits.LATB2 = 1; } while(0)
#define DIN2_SetLow()             do { LATBbits.LATB2 = 0; } while(0)
#define DIN2_Toggle()             do { LATBbits.LATB2 = ~LATBbits.LATB2; } while(0)
#define DIN2_GetValue()           PORTBbits.RB2
#define DIN2_SetDigitalInput()    do { TRISBbits.TRISB2 = 1; } while(0)
#define DIN2_SetDigitalOutput()   do { TRISBbits.TRISB2 = 0; } while(0)
#define DIN2_SetPullup()          do { WPUBbits.WPUB2 = 1; } while(0)
#define DIN2_ResetPullup()        do { WPUBbits.WPUB2 = 0; } while(0)
#define DIN2_SetPushPull()        do { ODCONBbits.ODCB2 = 0; } while(0)
#define DIN2_SetOpenDrain()       do { ODCONBbits.ODCB2 = 1; } while(0)
#define DIN2_SetAnalogMode()      do { ANSELBbits.ANSELB2 = 1; } while(0)
#define DIN2_SetDigitalMode()     do { ANSELBbits.ANSELB2 = 0; } while(0)
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

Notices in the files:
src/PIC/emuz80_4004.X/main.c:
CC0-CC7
